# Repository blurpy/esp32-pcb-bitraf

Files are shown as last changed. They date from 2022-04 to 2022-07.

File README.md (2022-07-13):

# esp32-pcb-bitraf

ESP32 S2 Mini Development Board PCB created with KiCad 6 at Bitraf workshop, to be ordered from PCBWay.

Reference PCB for the workshop available here: https://github.com/jenschr/ESP32-workshop-files

Inspired by the official development board [ESP32-S2-DevKitM-1](https://docs.espressif.com/projects/esp-idf/en/v4.4/esp32s2/hw-reference/esp32s2/user-guide-devkitm-1-v1.html).

### Features

* Reset switch
* Boot switch for entering programming mode
* Power LED
* General purpose LED
* [DotStar LED](https://learn.adafruit.com/adafruit-dotstar-leds/overview)
* USB-C for power and programming
* Fits on a breadboard

### Board

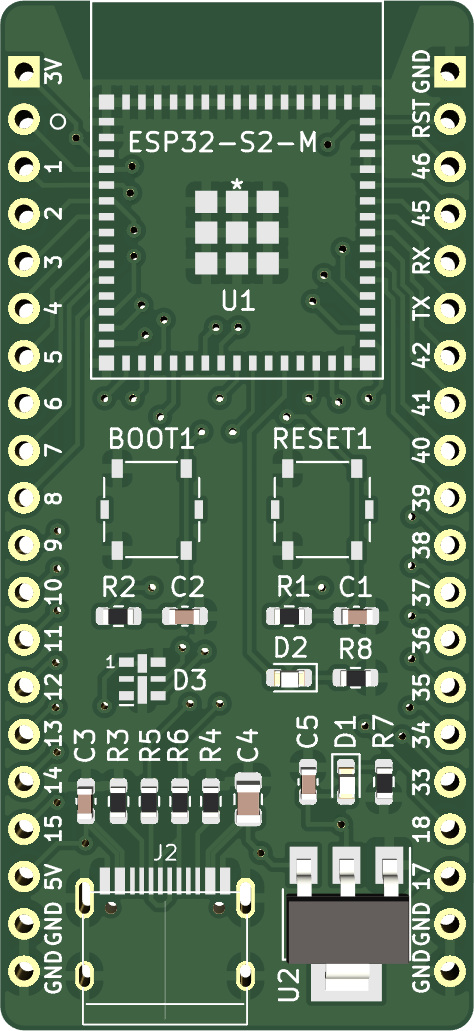
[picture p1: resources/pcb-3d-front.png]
PCB front

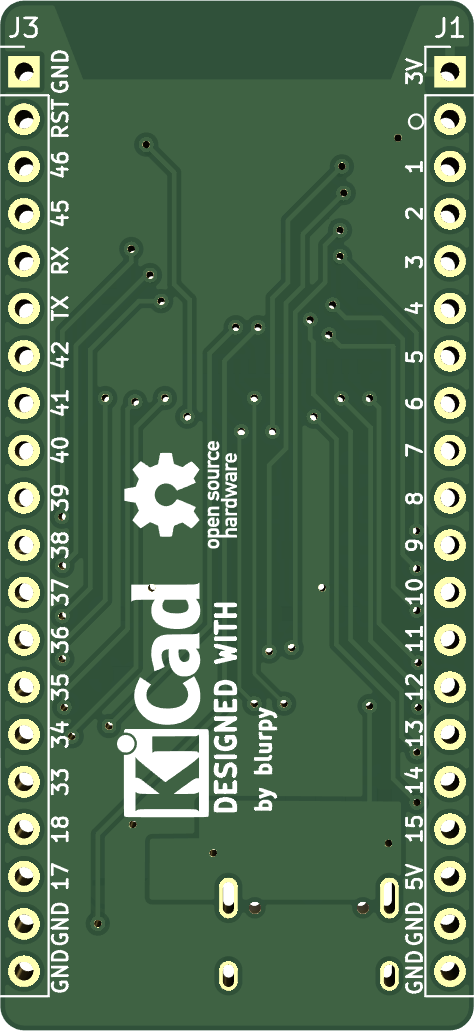
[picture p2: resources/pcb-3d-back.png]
PCB back


### Schematic

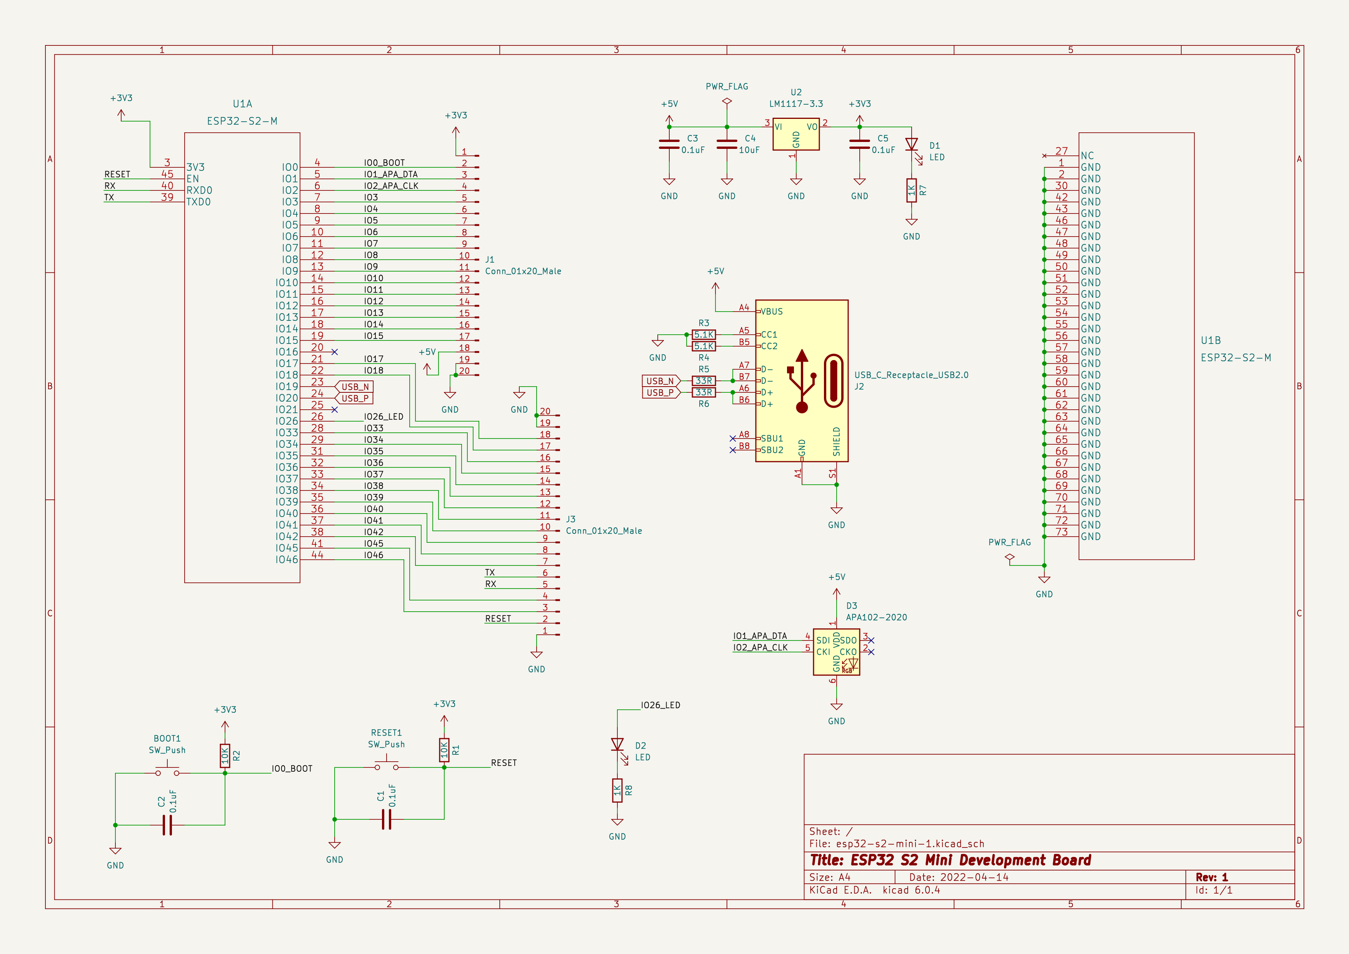
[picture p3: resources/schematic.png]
Schematic


### Bill of materials

Also available as an [interactive bom](https://blurpy.github.io/esp32-pcb-bitraf/bom/ibom.html).

| Item | Qty | Reference(s) | Value | Type | Footprint | Datasheet |
|---|-----|---|---|---|---|---|
| 1 | 2 | BOOT1, RESET1  | SW_Push | Switch | SW_SPST_Panasonic_EVQPL_3PL_5PL_PT_A08 | ~ |
| 2 | 4 | C1, C2, C3, C5 | 0.1uF | Capacitor | 0603_1608Metric | ~ |
| 3 | 1 | C4 | 10uF | Capacitor | 0805_2012Metric | ~ |
| 4 | 2 | D1, D2 | LED | LED | 0603_1608Metric | ~ |
| 5 | 1 | D3 | APA102-2020 | DotStar LED | APA102-2020 | https://www.led-color.com/upload/201604/APA102-2020%20SMD%20LED.pdf |
| 6 | 2 | J1, J3 | Conn_01x20_Male | Header | PinHeader_1x20_P2.54mm_Vertical | ~ |
| 7 | 1 | J2 | USB_C_Receptacle_USB2.0 | USB-C Connector  | TYPE-C-31-M-12 | https://www.usb.org/sites/default/files/documents/usb_type-c.zip |
| 8 | 2 | R1, R2 | 10K | Resistor | 0603_1608Metric | ~ |
| 9 | 2 | R3, R4 | 5.1K | Resistor | 0603_1608Metric | ~ |
| 10 | 2 | R5, R6 | 33R | Resistor | 0603_1608Metric | ~ |
| 11 | 2 | R7, R8 | 1K | Resistor | 0603_1608Metric | ~ |
| 12 | 1 | U1 | ESP32-S2-M | Microcontroller  | ESP32-S2-MINI-1-N4 | https://www.espressif.com/sites/default/files/documentation/esp32-s2-mini-1_esp32-s2-mini-1u_datasheet_en.pdf |
| 13 | 1 | U2 | LM1117-3.3 | Linear Regulator | SOT-223 | https://www.ti.com/lit/ds/symlink/lm1117.pdf |

### Libraries

* [USB TYPE-C-31-M-12 from Korean Hroparts Elec @ LCSC](https://github.com/jenschr/USB-C-Connectors)
  *  Available here: https://lcsc.com/product-detail/USB-Connectors_Korean-Hroparts-Elec-TYPE-C-31-M-12_C165948.html
* [Espressif Systems ESP32-S2-MINI-1-N4](https://app.ultralibrarian.com/details/e7064ac7-afcb-11eb-9033-0a34d6323d74/Espressif-Systems/ESP32-S2-MINI-1-N4)
  * Symbol Pin Ordering: Functional
  * Footprint Units: English (mil)

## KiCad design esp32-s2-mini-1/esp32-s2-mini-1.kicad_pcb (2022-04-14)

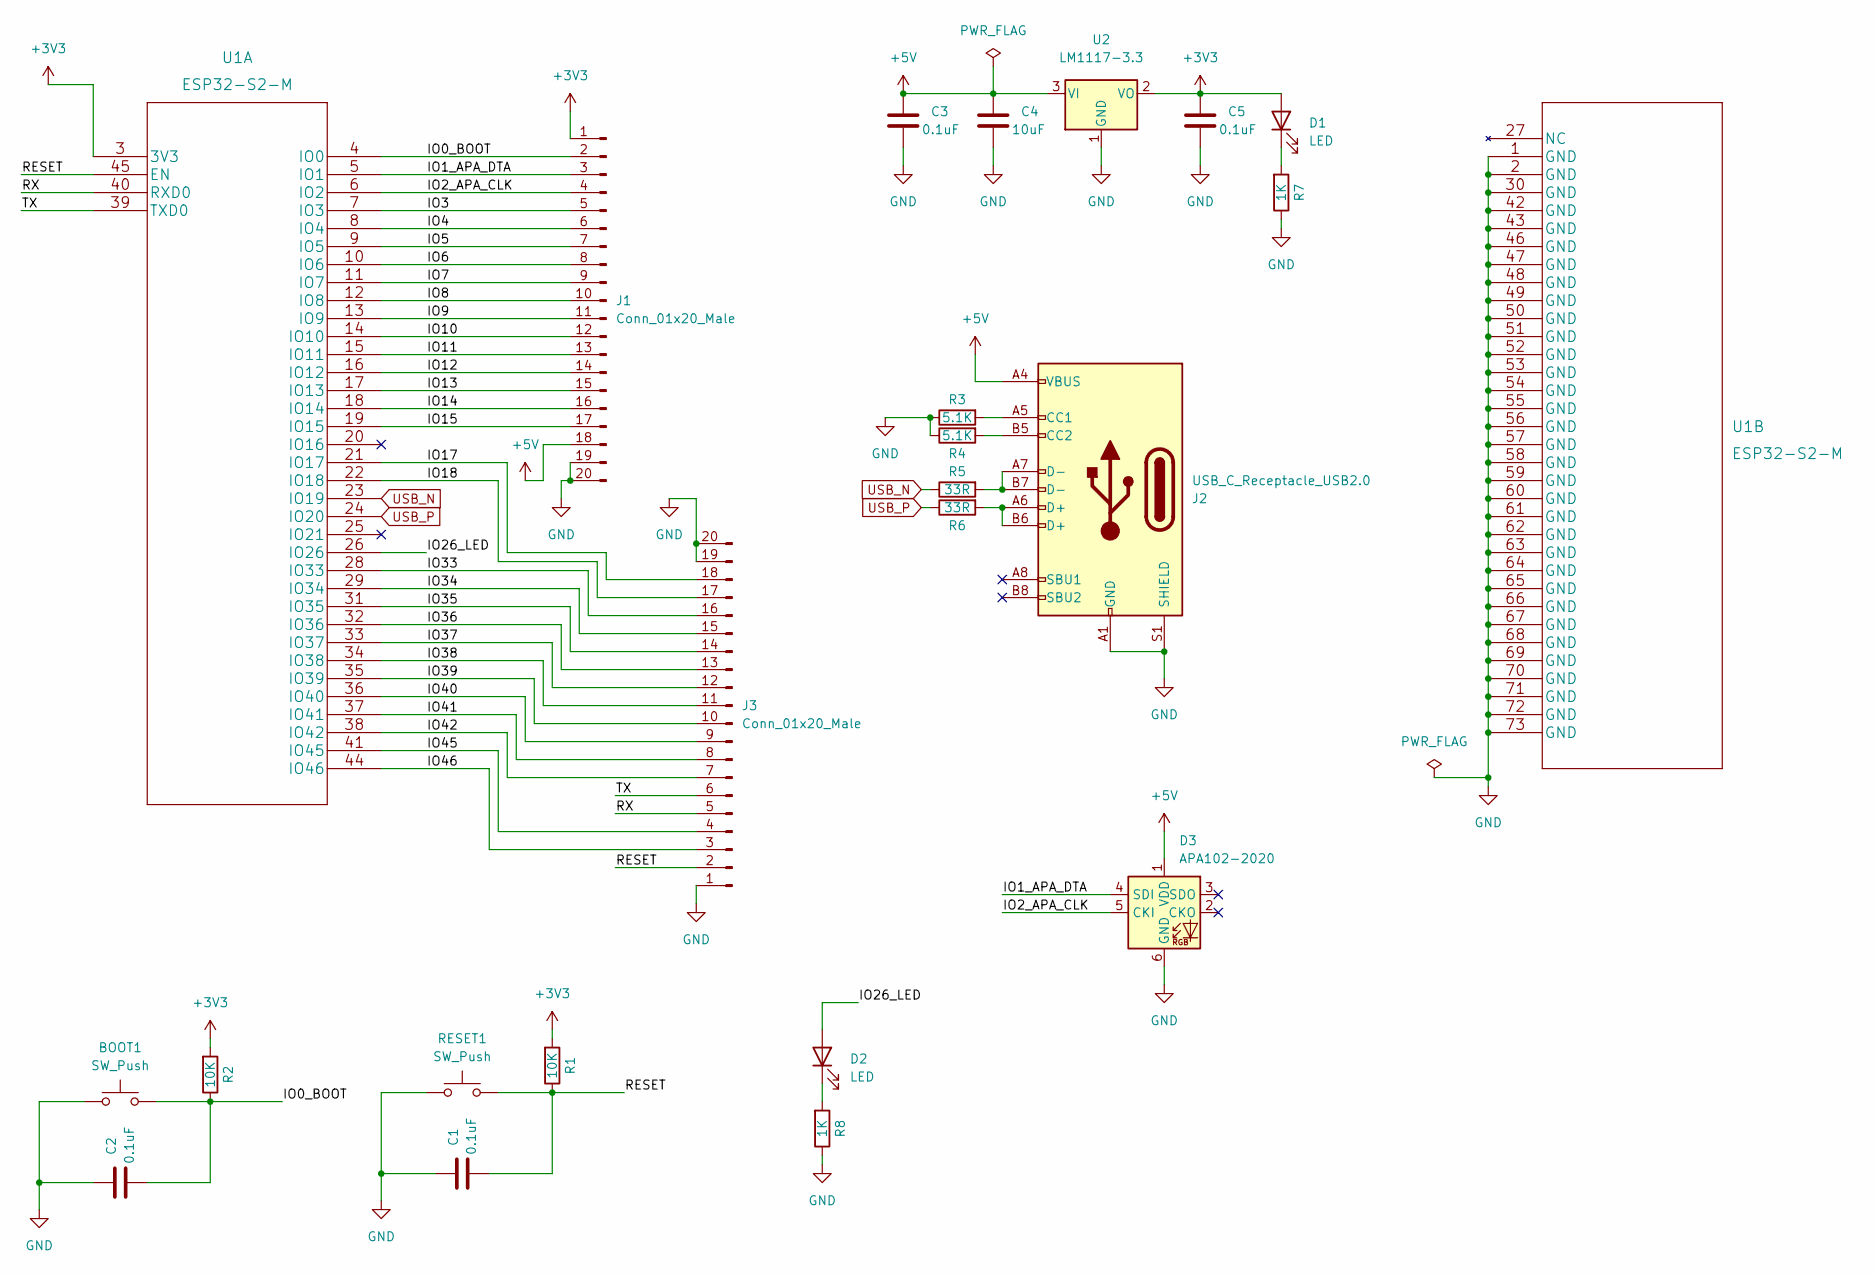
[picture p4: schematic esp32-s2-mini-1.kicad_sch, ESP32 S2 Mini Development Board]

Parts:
BOOT1: SW_Push; SW_SPST_Panasonic_EVQPL_3PL_5PL_PT_A08
C1, C2, C3, C5: 0.1uF; C_0603_1608Metric
C4: 10uF; C_0805_2012Metric
D1, D2: LED; LED_0603_1608Metric
D3: APA102-2020; LED-APA102-2020
J1, J3: Conn_01x20_Male; PinHeader_1x20_P2.54mm_Vertical
J2: USB_C_Receptacle_USB2.0; TYPE-C-31-M-12
R1, R2: 10K; R_0603_1608Metric
R3, R4: 5.1K; R_0603_1608Metric
R5, R6: 33R; R_0603_1608Metric
R7, R8: 1K; R_0603_1608Metric
RESET1: SW_Push; SW_SPST_Panasonic_EVQPL_3PL_5PL_PT_A08
U1: ESP32-S2-M; ESP32-S2-MINI-1-N4
U2: LM1117-3.3; SOT-223

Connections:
+3V3: C5.1, D1.2 (A), J1.1, R1.2, R2.2, U1.3 (3V3), U2.2 (VO)
+5V: C3.1, C4.1, D3.1 (VDD), J1.18, J2.A4 (VBUS), J2.A9 (VBUS), J2.B4 (VBUS), J2.B9 (VBUS), U2.3 (VI)
/IO0_BOOT: BOOT1.2, C2.2, J1.2, R2.1, U1.4 (IO0)
/IO1_APA_DTA: D3.4 (SDI), J1.3, U1.5 (IO1)
/IO2_APA_CLK: D3.5 (CKI), J1.4, U1.6 (IO2)
/IO3: J1.5, U1.7 (IO3)
/IO4: J1.6, U1.8 (IO4)
/IO5: J1.7, U1.9 (IO5)
/IO6: J1.8, U1.10 (IO6)
/IO7: J1.9, U1.11 (IO7)
/IO8: J1.10, U1.12 (IO8)
/IO9: J1.11, U1.13 (IO9)
/IO10: J1.12, U1.14 (IO10)
/IO11: J1.13, U1.15 (IO11)
/IO12: J1.14, U1.16 (IO12)
/IO13: J1.15, U1.17 (IO13)
/IO14: J1.16, U1.18 (IO14)
/IO15: J1.17, U1.19 (IO15)
/IO17: J3.18, U1.21 (IO17)
/IO18: J3.17, U1.22 (IO18)
/IO26_LED: D2.2 (A), U1.26 (IO26)
/IO33: J3.16, U1.28 (IO33)
/IO34: J3.15, U1.29 (IO34)
/IO35: J3.14, U1.31 (IO35)
/IO36: J3.13, U1.32 (IO36)
/IO37: J3.12, U1.33 (IO37)
/IO38: J3.11, U1.34 (IO38)
/IO39: J3.10, U1.35 (IO39)
/IO40: J3.9, U1.36 (IO40)
/IO41: J3.8, U1.37 (IO41)
/IO42: J3.7, U1.38 (IO42)
/IO45: J3.4, U1.41 (IO45)
/IO46: J3.3, U1.44 (IO46)
/RESET: C1.2, J3.2, R1.1, RESET1.2, U1.45 (EN)
/RX: J3.5, U1.40 (RXD0)
/TX: J3.6, U1.39 (TXD0)
GND: BOOT1.1, C1.1, C2.1, C3.2, C4.2, C5.2, D3.6 (GND), J1.19, J1.20, J2.A1 (GND), J2.A12 (GND), J2.B1 (GND), J2.B12 (GND), J2.S1 (SHIELD), J3.1, J3.19, J3.20, R3.1, R4.1, R7.1, R8.1, RESET1.1, U1.1 (GND), U1.2 (GND), U1.30 (GND), U1.42 (GND), U1.43 (GND), U1.46 (GND), U1.47 (GND), U1.48 (GND), U1.49 (GND), U1.50 (GND), U1.51 (GND), U1.52 (GND), U1.53 (GND), U1.54 (GND), U1.55 (GND), U1.56 (GND), U1.57 (GND), U1.58 (GND), U1.59 (GND), U1.60 (GND), U1.61 (GND), U1.62 (GND), U1.63 (GND), U1.64 (GND), U1.65 (GND), U1.66 (GND), U1.67 (GND), U1.68 (GND), U1.69 (GND), U1.70 (GND), U1.71 (GND), U1.72 (GND), U1.73 (GND), U2.1 (GND)
unnamed: D1.1 (K), R7.2
unnamed: D2.1 (K), R8.2
unnamed: J2.A5 (CC1), R3.2
unnamed: J2.A6 (D+), J2.B6 (D+), R6.2
unnamed: J2.A7 (D-), J2.B7 (D-), R5.2
unnamed: J2.B5 (CC2), R4.2
USB_N: R5.1, U1.23 (IO19)
USB_P: R6.1, U1.24 (IO20)

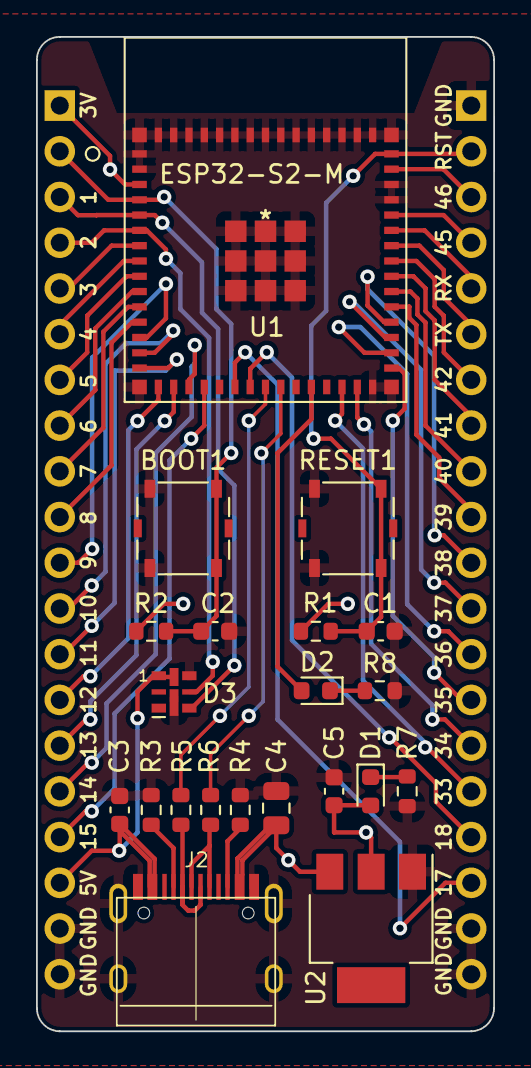
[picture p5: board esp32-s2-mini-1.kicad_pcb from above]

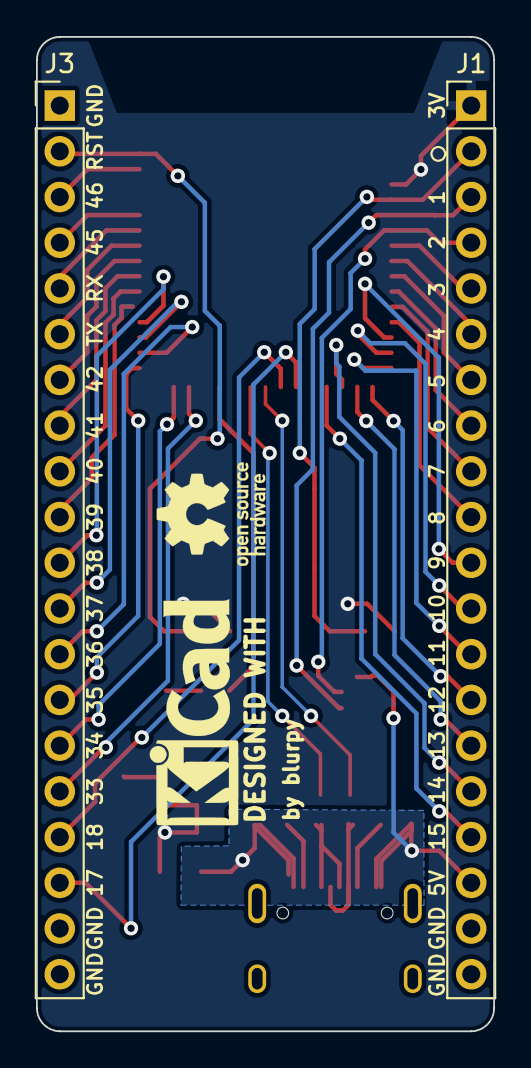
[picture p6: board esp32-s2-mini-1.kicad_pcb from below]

Board: 2 copper layers, 25.4 x 55.2 mm, 23 parts (2 on the bottom side), 45 nets.

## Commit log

2022-04-03 Adding files created during the workshop, and the required libraries
    [esp32-s2-mini-1.kicad_pcb, esp32-s2-mini-1.kicad_sch]
2022-04-03 Remove master from folder name of usb-c-connectors library
2022-04-03 Seems some labels were missing from original saves
    [esp32-s2-mini-1.kicad_sch]
2022-04-10 The basic structure of the pcb is ready. Pins are unconnected, and extra components are missing still.
    [esp32-s2-mini-1.kicad_pcb, esp32-s2-mini-1.kicad_sch]
2022-04-11 Add power LED
    [esp32-s2-mini-1.kicad_pcb, esp32-s2-mini-1.kicad_sch]
2022-04-12 Add controllable LED, dotstar LED, and connect everything
    [esp32-s2-mini-1.kicad_pcb, esp32-s2-mini-1.kicad_sch]
2022-04-13 Adding labels to pins in the schematic
    [esp32-s2-mini-1.kicad_pcb, esp32-s2-mini-1.kicad_sch]
2022-04-13 Tidy up schematic a bit
    [esp32-s2-mini-1.kicad_sch]
2022-04-13 Adding labels to half the pins on the pcb front
    [esp32-s2-mini-1.kicad_pcb]
2022-04-13 Adding labels to the other half the pins on the pcb front
    [esp32-s2-mini-1.kicad_pcb]
2022-04-13 Adding labels to the pins on the pcb back
    [esp32-s2-mini-1.kicad_pcb]
2022-04-13 Add signature and logos to the pcb back
    [esp32-s2-mini-1.kicad_pcb]
2022-04-14 Adding a title and date to the schematic
    [esp32-s2-mini-1.kicad_sch]
2022-04-14 Marking the logos on the back as "not in schematic" to avoid them being removed when updating the pcb from schematic
    [esp32-s2-mini-1.kicad_pcb]
2022-04-14 Changing clearance from 0.2mm to 0.18mm since it's used by the dotstar LED and it should work
    [esp32-s2-mini-1.kicad_pcb]
2022-04-14 Add gerbers and drill files
    [esp32-s2-mini-1-B_Cu.gbr, esp32-s2-mini-1-B_Mask.gbr, esp32-s2-mini-1-B_Paste.gbr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]
2022-04-14 Updated readme with pictures and bom
2022-07-13 Adding interactive bom
2022-07-13 Add link to interactive bom
2022-07-13 Add link to USB-C connector

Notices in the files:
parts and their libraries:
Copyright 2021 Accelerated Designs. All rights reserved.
